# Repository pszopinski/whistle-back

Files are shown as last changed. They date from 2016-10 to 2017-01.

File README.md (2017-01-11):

# Whistle Back
Urządzenie nasłuchujące melodię z otoczenia i odwzorowujące ją za pomocą 
brzęczyka.

## Potrzebne elementy
W projekcie wykorzystuję:
* [klon Arduino Micro][arduino-ali] wyposażony w mikrokontroler [ATmega32U4][atmega] i 2,5&nbsp;kB pamięci SRAM,
* [mikrofon elektretowy ze wzmacniaczem MAX4466][mic-ali] pracujący z napięciem 2.4&nbsp;V &ndash; 5.5&nbsp;V,
* [brzęczyk piezoelektryczny][buzzer-ali] bez wbudowanego generatora sygnału,
* płytkę stykową z 400 otworami,
* przycisk monostabilny,
* przewody połączeniowe.

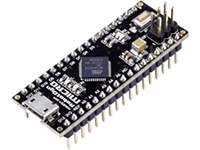
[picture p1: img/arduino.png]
obrazek klonu Arduino Micro
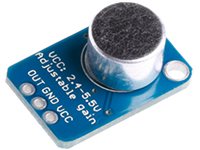
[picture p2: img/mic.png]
obrazek mikrofonu
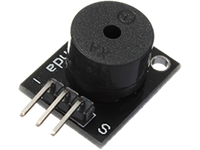
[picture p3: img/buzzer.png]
obrazek brzęczyka
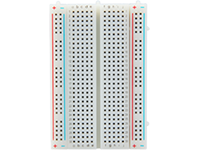
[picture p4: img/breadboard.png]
obrazek płytki stykowej
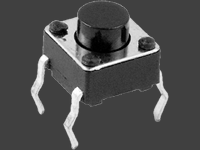
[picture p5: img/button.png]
obrazek przycisku
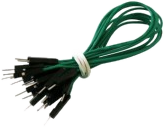
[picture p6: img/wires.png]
obrazek przewodów


Zdecydowałem się wykorzystać platformę Arduino Micro między innymi dlatego, że pozwala na zasilanie urządzeń peryferyjnych napięciem 3,3&nbsp;V. Mikrofon zasilany takim napięciem charakteryzuje się większą czułością, niż w przypadku zastosowania napięcia 5&nbsp;V.

## Funkcjonalność
Urządzenie pracuje według następującego schematu.

1. Oczekiwanie na naciśnięcie przycisku.
2. Nagrywanie melodii z otoczenia.
3. Dla każdej z próbek czasowych:
  1. Przeprowadzenie transformaty Fouriera.
  2. Zapisanie odpowiedniego sygnału wyjściowego.
4. Odtworzenie sygnału wyjściowego.
5. Powrót do punktu 1.

## Lista zadań
Aby ułatwić sobie pracę, przygotowałem listę czynności, które należy wykonać.
- [x] Zakup potrzebnych elementów.
- [x] Implementacja rekurencyjnego algorytmu FFT w języku Python.
- [x] Implementacja algorytmu Cooleya-Tukeya w języku C.
- [x] Test współpracy klonu Arduino z Arduino IDE.
- [x] Przylutowanie pinów modułu mikrofonu.
- [x] Złożenie układu na płytce stykowej.
- [x] Podstawowa obsługa przycisku.
- [x] Podstawowa obsługa brzęczyka.
- [x] Podstawowa obsługa mikrofonu.
- [x] Obsługa rozpoczęcia i zakończenia nagrywania.
- [x] Wykonywanie transformat Fouriera.
- [x] Generowanie adekwatnego sygnału wyjściowego.

## Opis użytego algorytmu
Wykorzystałem najbardziej powszechną formę algorytmu Cooleya–Turkeya, Radix-2. Polega ona na obliczeniu transformat indeksów parzystych i nieparzystych osobno, a następnie połączeniu danych. Przyspieszanie obliczeń osiąga się przy wykorzystaniu okresowości transformaty Fouriera.

W trakcie działania algorytmu zamienianie kolejności wyliczonych wartości nie jest wykonywane po każdym etapie transformaty. W wyniku tego otrzymuje się tablicę z indeksami w kolejności **odwróconych bitów**. W mojej implementacji dokonuję zmiany kolejności indeksów na końcu.

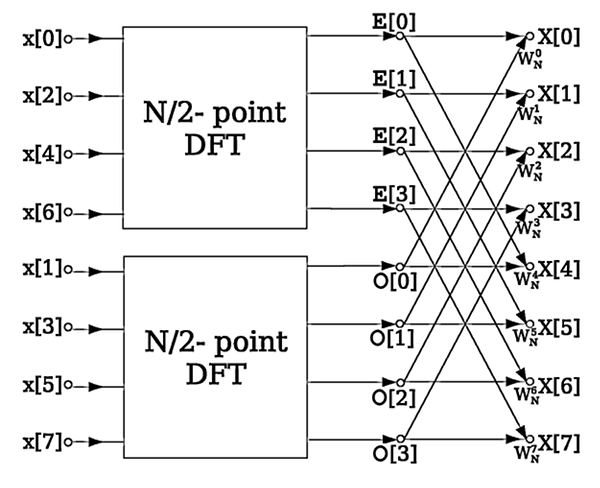
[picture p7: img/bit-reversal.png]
diagram wykonywania FFT


## Złożenie układu na płytce stykowej
Złożyłem układ tak, jak przedstawione jest to na poniższym diagramie.

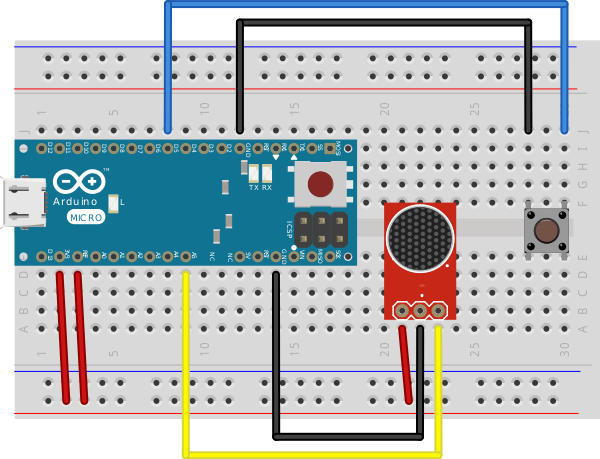
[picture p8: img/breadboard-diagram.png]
diagram płytki stykowej


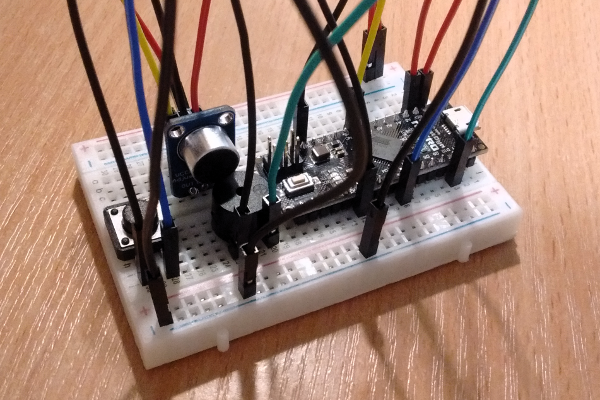
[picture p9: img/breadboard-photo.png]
zdjęcie płytki stykowej


Mikrofon zasilany jest napięciem 3,3&nbsp;V. Pin 3V3 połączony jest również z pinem REF dlatego, że czytamy wartości analogowe z mikrofonu właśnie o takim napięciu. Pin przycisku (D5) został skonfigurowany jako INPUT_PULLUP.

## Odczytywanie danych z mikrofonu
Tak skonfigurowany układ jest w stanie poprawnie odczytywać sygnał z mikrofonu, co widać na poniższych zrzutach ekranu.

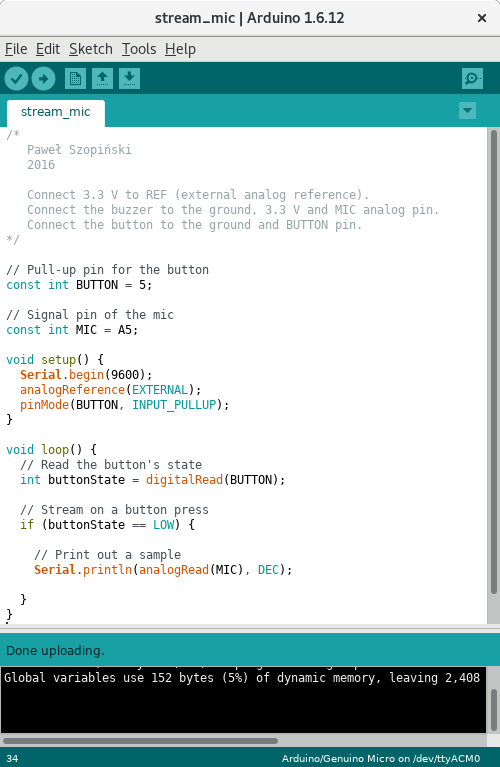
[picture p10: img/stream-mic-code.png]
zrzut ekranu projektu stream_mic


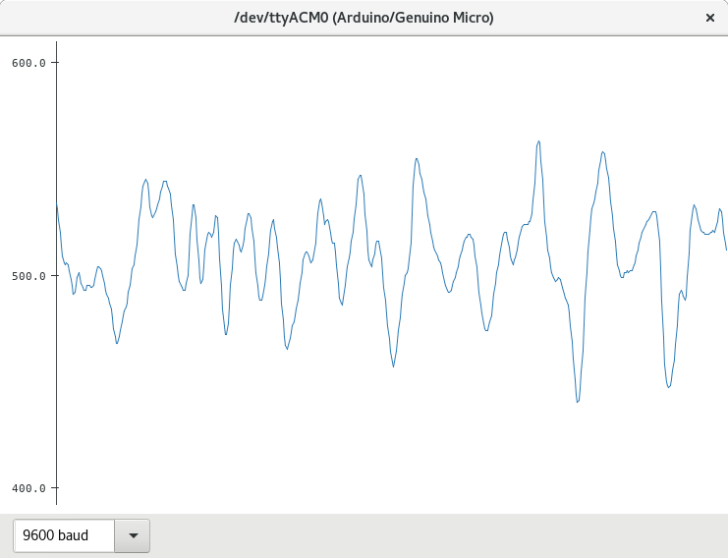
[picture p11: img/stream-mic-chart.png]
wykres wartości zwracanych przez układ


## Ograniczenia Arduino
Arduino Micro posiada 2,5&nbsp;kB pamięci RAM, a jedna liczba zespolona zajmuje 8&nbsp;B. Maksymalnie przechowywać w pamięci możemy więc około 300 próbek. Dodając ograniczenie implementacji algorytmu FFT na tablice próbek długości 2<sup>N</sup> i potrzebę stworzenia drugiej tablicy tej samej długości, maksymalnie możemy przechowywać w pamięci 128 próbek.

## Projekty Arduino
W projekcie *fft_buzzer* zaimplementowałem pełną funkcjonalność.

Projekty *fft* i *fft_continuous* zawierają implementację algorytmu FFT. Projekt *stream_mic* zawiera obsługę mikrofonu.

## Napotkane trudności
Podczas rozwoju projektu musiałem rozwiązać wiele problemów. Były to między innymi nieprawidłowe wyniki obliczeń wynikające z przekroczenia zakresu i propagacji błędów reprezentacji zmiennoprzecinkowej. Musiałem również nauczyć się poprawnie korzystać z danych przechowywanych w pamięci programu za pomocą słowa kluczowego **PROGMEM**.

Kluczowym okazało podłączenie styku GND mikrofonu do osobnego pinu mikrokontrolera. W w przeciwnym wypadku mikrofon odczytywał sygnał przesunięty o pewną stałą wartość.

Precyzyjne odczytanie (i odtworzenie) częstotliwości sprawia problemy.

## Źródła
Odnośniki na obrazkach prowadzą do ich źródła.

[Diagram](https://commons.wikimedia.org/wiki/File:DIT-FFT-butterfly.png) przedstawiający wykonywanie FFT został stworzony przez użytkownika Virens.

Diagram układu przygotowałem w programie [Fritzing](http://fritzing.org/home/).

## Bibliografia
* [Fast Fourier Transforms](http://www.katjaas.nl/FFT/FFT.html) [dostęp: 2016-11-8]  
  obrazowe przedstawienie sposobu działania i implementacji algorytmu Colleya-Turkeya
* [Cooley&ndash;Tukey FFT algorithm](https://en.wikipedia.org/wiki/Cooley–Tukey_FFT_algorithm) [dostęp: 2016-11-8]  
  artykuł w Wikipedii
* [Szeregi i transformaty Fouriera](http://www.icsr.agh.edu.pl/~mownit/output/pdf/fourier.pdf) [dostęp: 2016-11-8]  
  notatki do wykładu z MOwNiT-u dra Bubaka
* R. Burden, J. Faires. Numerical Analysis. Edycja 9. Strony 547&ndash;557.  
  rozdział o szybkiej transformacie Fouriera
* [Arduino - Reference](https://www.arduino.cc/en/Reference/HomePage) [dostęp: 2016-12-06]  
  dokumentacja języka programowania Arduino

***

Paweł Szopiński
    
[arduino-ali]: https://www.aliexpress.com/item/Micro-ATmega32U4-5V-16MHz-Pins-soldered-Compatible-with-Arduino-Micro-and-Leonardo/32676998690.html
[atmega]: http://www.atmel.com/devices/atmega32u4.aspx
[mic-ali]: https://www.aliexpress.com/item/New-Electret-Microphone-Amplifier-MAX4466-With-Adjustable-Gain-For-Arduino/32717091448.html
[buzzer-ali]: https://www.aliexpress.com/item/Passive-Buzzer-Module-for-Arduino-AVR-PIC-Good-New-KY-006/32273623799.html

[arduino-img]: img/arduino.png
[mic-img]: img/mic.png
[buzzer-img]: img/buzzer.png
[breadboard-img]: img/breadboard.png
[button-img]: img/button.png
[wires-img]: img/wires.png

[bit-reversal]: img/bit-reversal.png

[breadboard-diagram]: img/breadboard-diagram.png
[breadboard-photo]: img/breadboard-photo.png

[stream-mic-code]: img/stream-mic-code.png
[stream-mic-chart]: img/stream-mic-chart.png

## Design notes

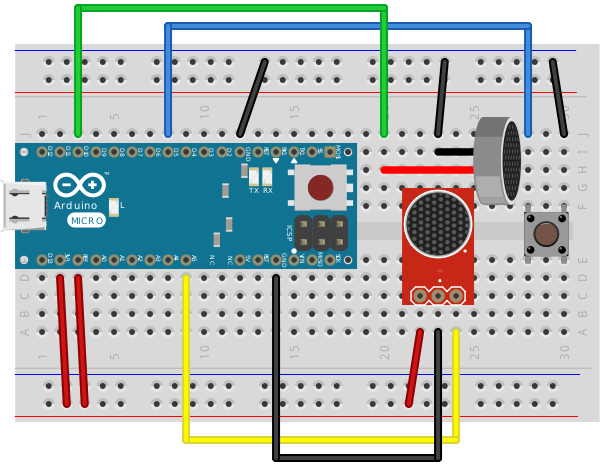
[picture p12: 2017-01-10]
Arduino/fft_buzzer/breadboard.png

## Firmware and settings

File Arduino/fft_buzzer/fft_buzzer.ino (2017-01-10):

#include "complex.h"
#include "fft.h"
/*
   Paweł Szopiński
   2016
*/

// Pull-up pin for the button
const int BUTTON = 5;

// Buzzer pin
const int BUZZER = 10;

// Signal pin of the mic
const int MIC = A5;

// Array for storing samples
Complex SAMPLES[FFT_CHUNK_SIZE];

// Array for storing results
const int LEN = 30;
double RESULTS[LEN];

void setup() {
  Serial.begin(9600);
  analogReference(EXTERNAL);
  pinMode(BUTTON, INPUT_PULLUP);
  pinMode(BUZZER, OUTPUT);
  pinMode(LED_BUILTIN, OUTPUT);
}

void loop() {
  if (digitalRead(BUTTON) == LOW) {

    // Turn the LED on
    digitalWrite(LED_BUILTIN, HIGH);
    Serial.print(F("Recording... "));

    for (int i = 0; i < LEN; i++) {
      // Record
      for (int j = 0; j < FFT_CHUNK_SIZE; j++) {
        SAMPLES[j] = Complex(analogRead(MIC));
      }

      // Do a FFT
      fft(SAMPLES);

      // Save the dominant frequency
      RESULTS[i] = dominant_frequency(SAMPLES);
      Serial.println(RESULTS[i]);
    }

    // Turn the LED off
    digitalWrite(LED_BUILTIN, LOW);
    Serial.print(F("Done. "));
    
    // Play a tune
    Serial.print(F("Playing... "));
    for (int i = 0; i < LEN; i++) {
      double frequency = RESULTS[i];
      if (frequency > 0) {
        tone(BUZZER, frequency);
      }
      delay(FFT_DURATION);
      noTone(BUZZER);
    }
    Serial.println(F("Done."));

    // Blink the LED
    digitalWrite(LED_BUILTIN, HIGH);
    delay(100);
    digitalWrite(LED_BUILTIN, LOW);
    delay(100);
  }
}

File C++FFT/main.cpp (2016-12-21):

#include <iostream>

#include "complex.h"
#include "fft.h"

int main() {
    Complex SAMPLES[FFT_CHUNK_SIZE] = {
        557,
        392,
        529,
        439,
        515,
        575,
        612,
        558,
        492,
        481,
        504,
        496,
        470,
        436,
        418,
        471,
        534,
        580,
        560,
        521,
        523,
        559,
        567,
        531,
        465,
        426,
        453,
        504,
        527,
        508,
        488,
        506,
        559,
        589,
        556,
        492,
        457,
        484,
        517,
        515,
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
    };
    
    fft(SAMPLES);
    
    for (int i = 1; i < FFT_CHUNK_SIZE / 2; i++) {
        std::cout << SAMPLES[i].modulus() << ", ";
    }
}

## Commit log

2016-12-06 Dodanie linku do dokumentacji języka Arduino
2016-12-06 Zmiana linku do Arduino Reference
2016-12-06 Dodanie paragrafu Ograniczenia Arduino
2016-12-06 Dodanie projektów Arduino
2016-12-21 Add working fft and fft_continuous Arduino projects
2017-01-10 Add the (almost) final version
    [breadboard.fzz]
